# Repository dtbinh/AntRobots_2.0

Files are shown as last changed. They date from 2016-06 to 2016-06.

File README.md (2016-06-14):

# Ant Robot 2.0 #
### Small mobile robots running on Raspberry Pi 2 created to study collective excavation in ant colonies ###

#### Contents of this repository: ####

```arduino_antrobots_2.0/src/``` contains arduino program

```arduino_antrobots_2.0/lib/``` contains library for HMC6343 (3 axis compass)

```CAD_files/``` contains all SolidWorks files

```src/``` contains main c++ raspi code

```Makefile``` contains recipe to compile code in ```src/```

```pixycam.prm``` contains setting for pixy camera

```raspi_setup.txt``` contains all documentation on setup and running

To compile follow these steps in this directory:
```
$ mkdir build		// create a build directory
$ make		        // compile or do 'make rebuild' to recomplie
$ sudo ./run		// run the code
```

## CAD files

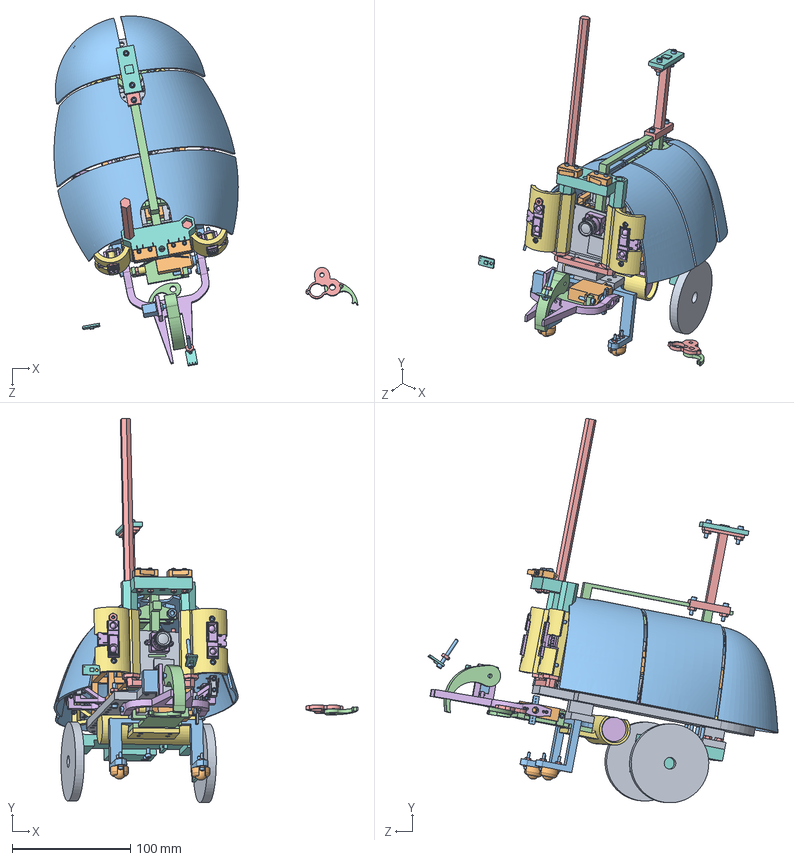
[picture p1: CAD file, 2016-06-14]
CAD_files/DiggerMk2v4d.SLDASM
256.7 x 324.8 x 295.7 mm
ArduinoMega
HS-A5076HB
HS A5076HB square servo hornSLDASM
claw x 2
micro claw base
gripper servo holder
head mount spacer
sparkfun line sensor x 2
Pixy_board
header_2x5ways
mini_usb_b_vertical_connector
RGB_led_CMS
switch-FSMRA6JH
M12_lens_holder
header3x2
header_MTA-100_2pins
pixy_lens
pan head cross recess screw_iso
outer shell 1
shell skeleton
front mount
IR Sensor x 2
front IR mount guard x 2
whisker mount
ModularBodyBase
Metal Ball Caster x 2
front caster holder
arm mount
gyro extention
new side adapter x 4
new side adapter back x 2
quickIMU
quick_switch x 6
quick_switch2 x 2
socket head cap screw_ai x 45
flat washer type a selected narrow_ai x 2
machine screw nut hex_ai x 43
dummy battery
batHolder
dummyWheel x 2
elecHolder
HS-55
grip_hook

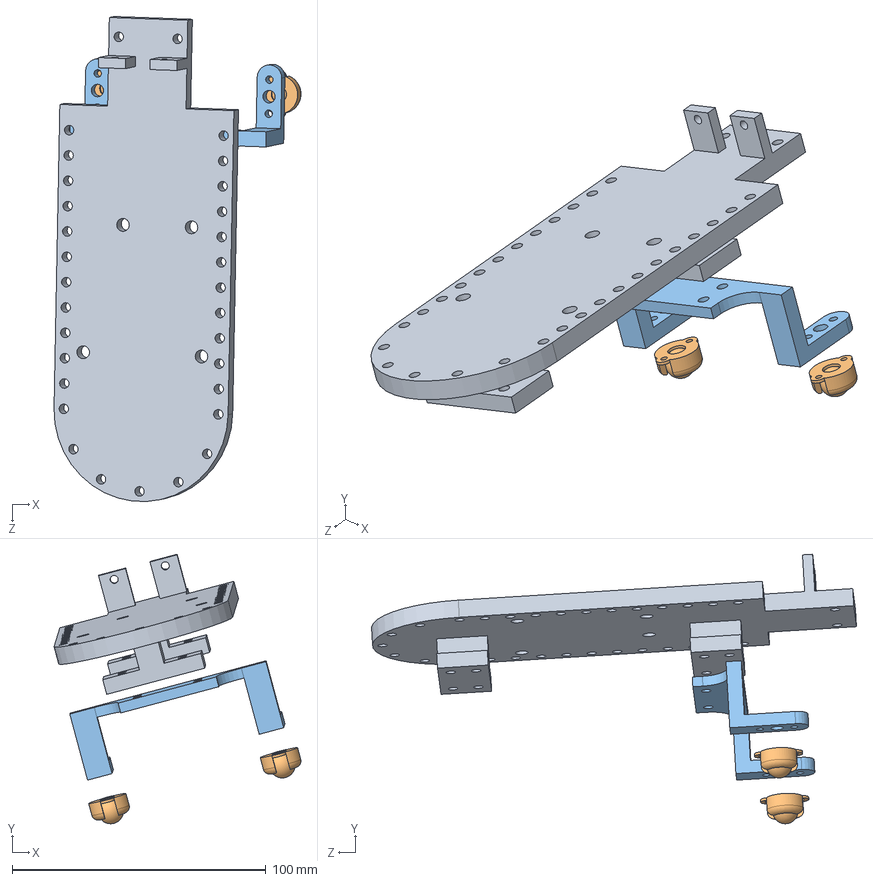
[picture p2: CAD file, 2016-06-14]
CAD_files/Body Assy.SLDASM
97.3 x 106.2 x 191.0 mm
ModularBodyBase
Metal Ball Caster x 2
front caster holder

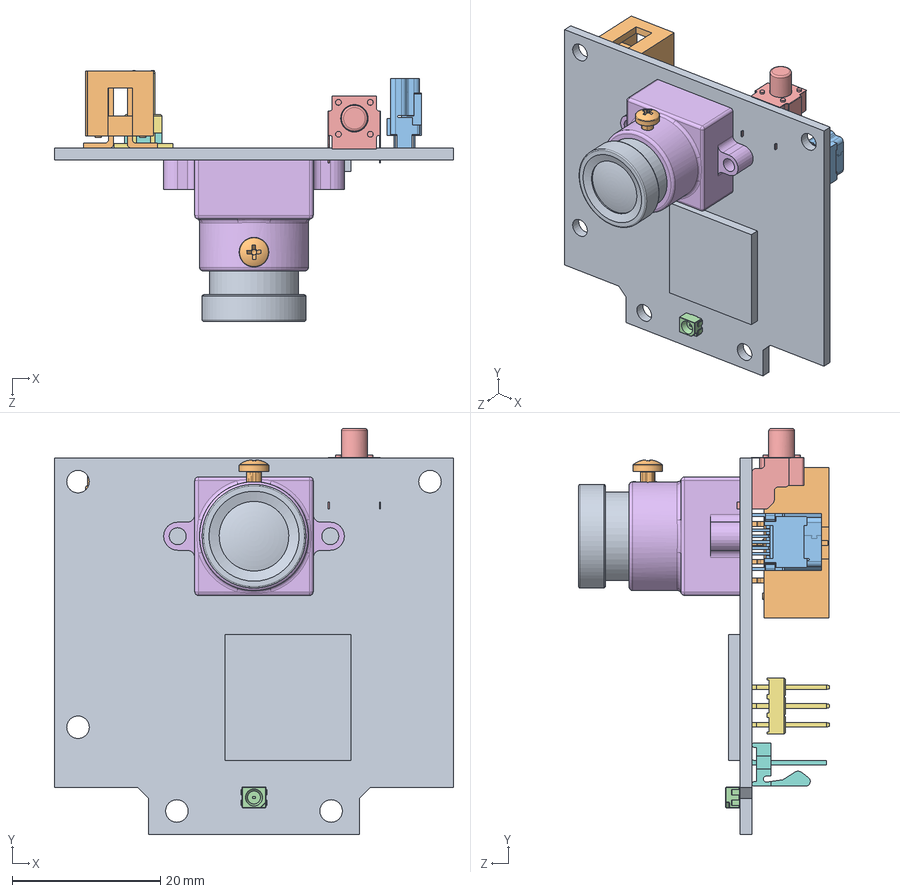
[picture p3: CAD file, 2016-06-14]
CAD_files/Pixy(CMUcam5).SLDASM
53.8 x 54.8 x 33.8 mm
Pixy_board
header_2x5ways
mini_usb_b_vertical_connector
RGB_led_CMS
switch-FSMRA6JH
M12_lens_holder
header3x2
header_MTA-100_2pins
pixy_lens
pan head cross recess screw_iso

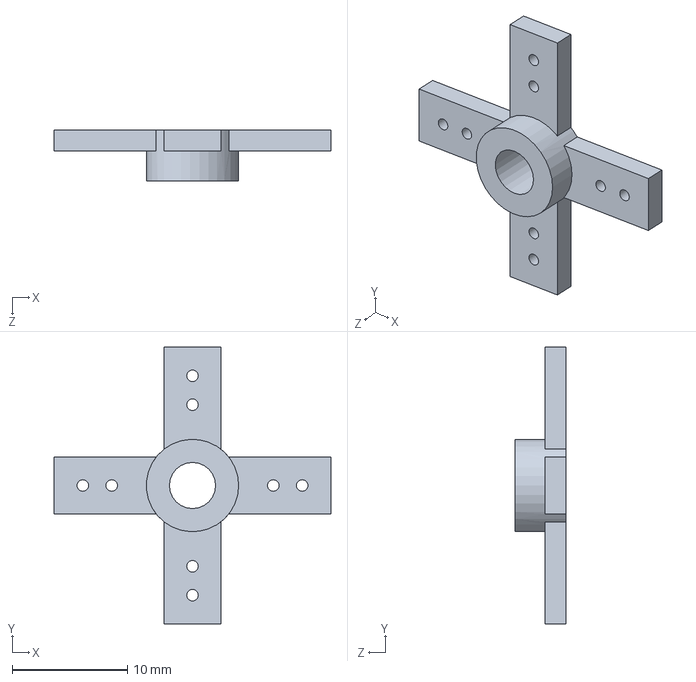
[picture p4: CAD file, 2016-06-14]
CAD_files/HS A5076HB square servo hornSLDASM.SLDPRT
24.0 x 24.0 x 4.40 mm

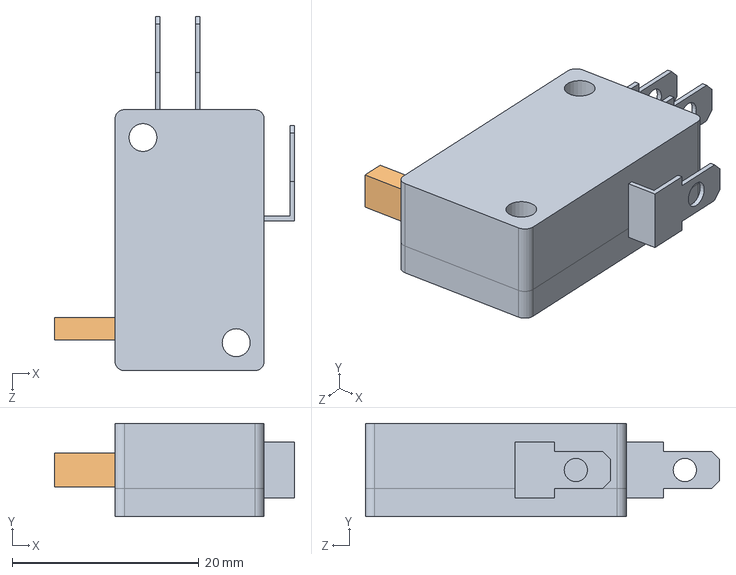
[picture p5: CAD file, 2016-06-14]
CAD_files/hacked limit switch assy.SLDASM
25.7 x 10.0 x 38.0 mm
limit switch body
switch hack

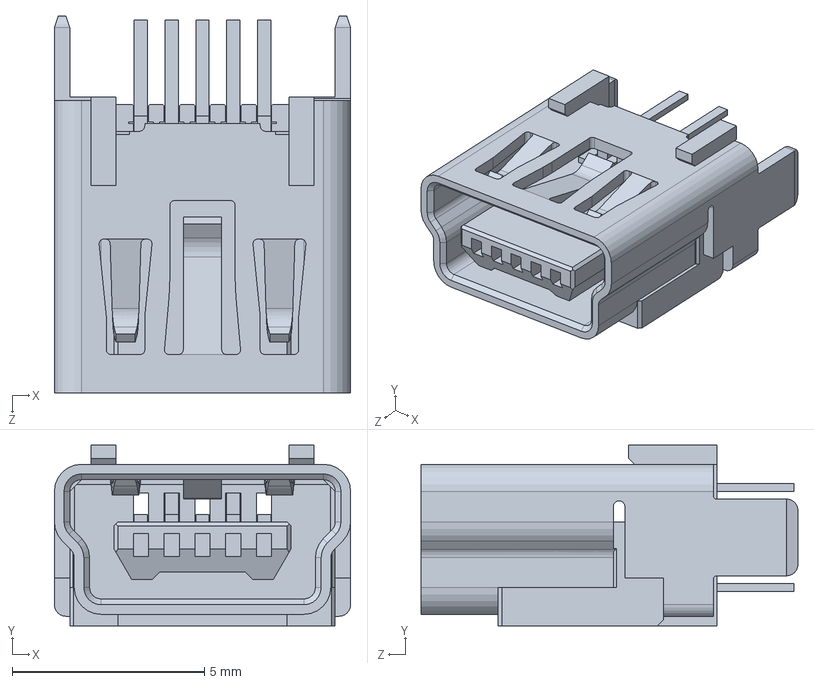
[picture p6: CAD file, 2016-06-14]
CAD_files/mini_usb_b_vertical_connector.SLDPRT
7.70 x 4.70 x 9.80 mm

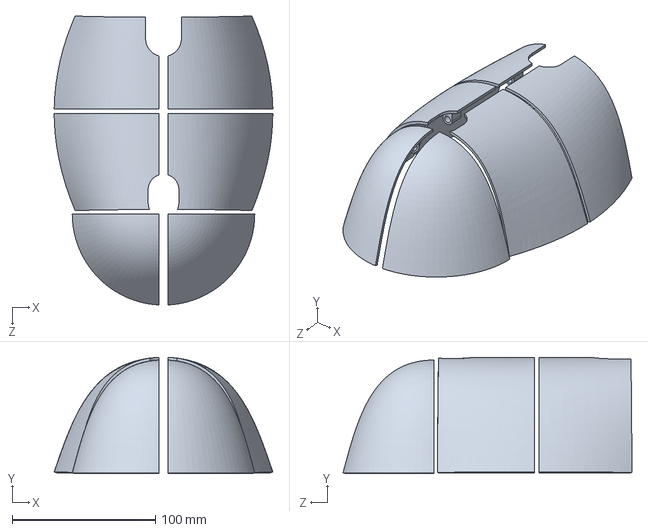
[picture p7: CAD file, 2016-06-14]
CAD_files/outer shell 1.SLDPRT
152.9 x 81.3 x 202.0 mm

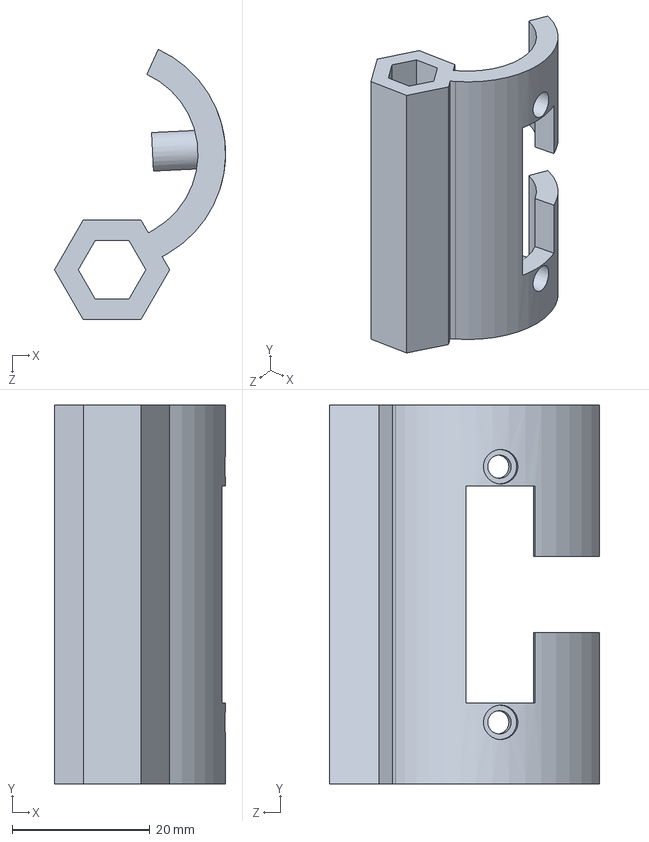
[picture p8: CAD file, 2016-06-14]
CAD_files/front IR mount guard.SLDPRT
24.8 x 55.0 x 39.2 mm

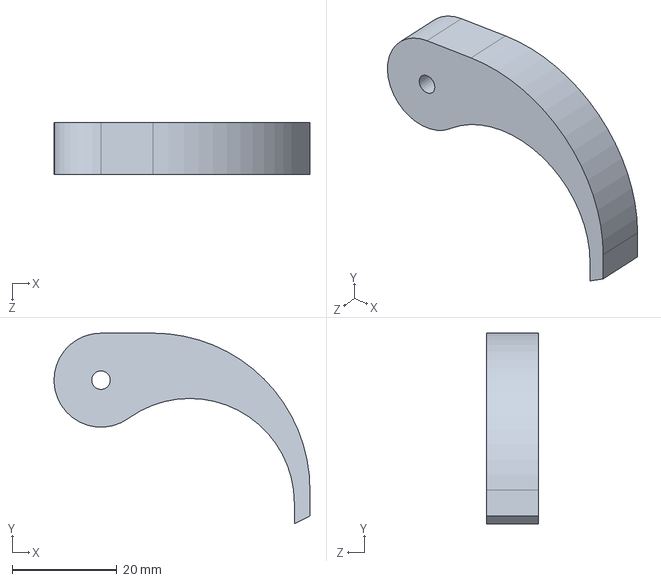
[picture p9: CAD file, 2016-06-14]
CAD_files/grip_hook.SLDPRT
49.0 x 36.5 x 10.0 mm

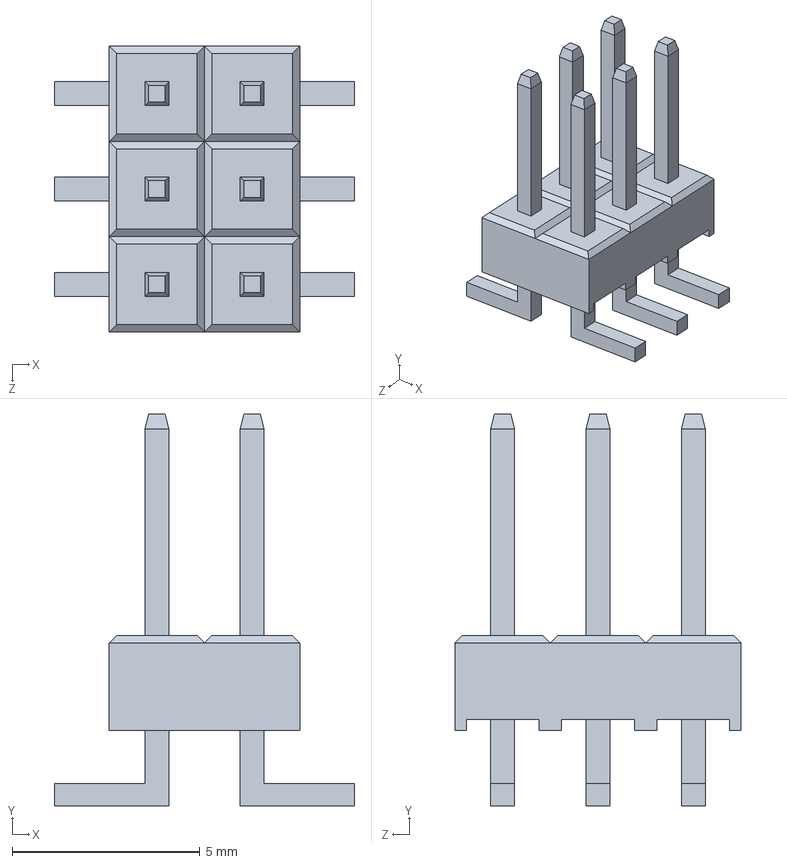
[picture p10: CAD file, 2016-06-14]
CAD_files/header3x2.SLDPRT
8.00 x 10.4 x 7.62 mm

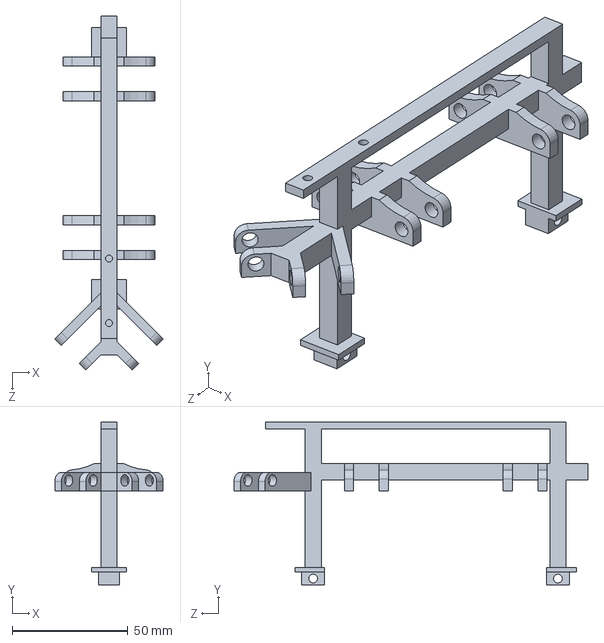
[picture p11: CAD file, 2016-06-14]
CAD_files/shell skeleton.SLDPRT
47.0 x 70.5 x 153.2 mm

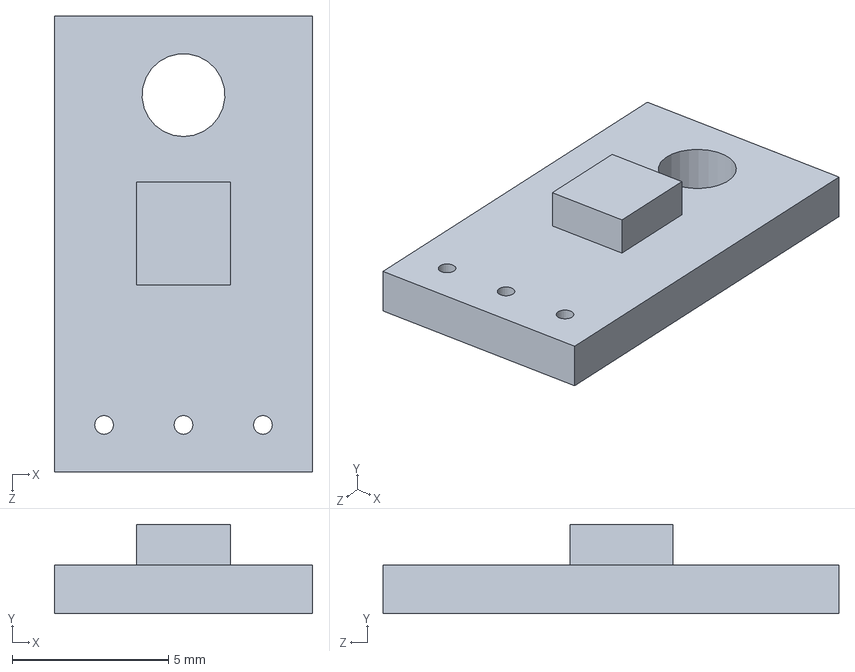
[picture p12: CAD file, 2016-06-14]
CAD_files/sparkfun line sensor.SLDPRT
8.25 x 2.85 x 14.6 mm

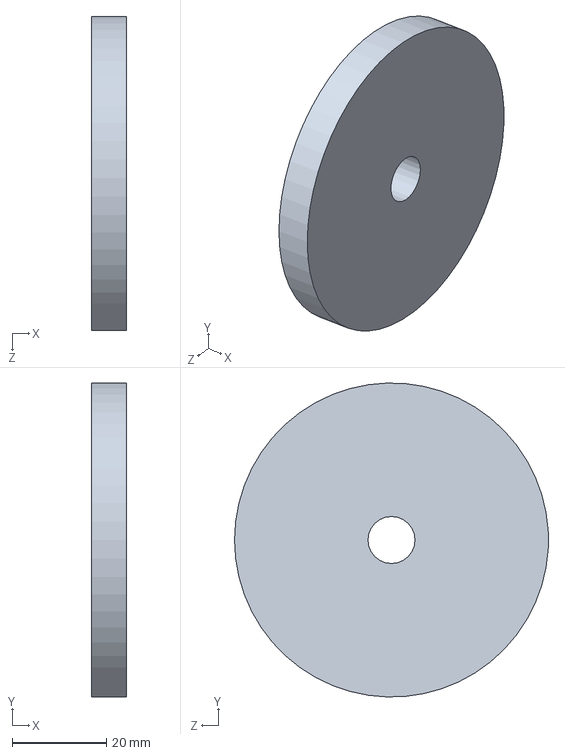
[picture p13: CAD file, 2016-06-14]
CAD_files/dummyWheel.SLDPRT
7.50 x 66.7 x 66.7 mm

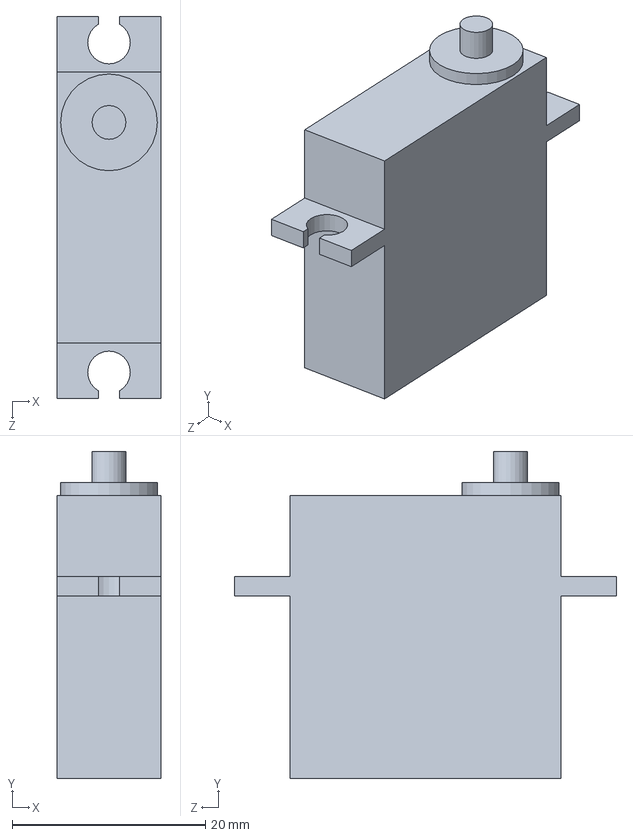
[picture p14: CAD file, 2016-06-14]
CAD_files/HS-A5076HB.SLDPRT
10.8 x 33.8 x 39.5 mm

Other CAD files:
CAD_files/Motor and Wheel.sldasm
CAD_files/ArduinoMega.SLDPRT
CAD_files/micro claw base.SLDPRT
CAD_files/new_ee_holder.SLDPRT
CAD_files/HS-55.SLDPRT
CAD_files/IR Sensor.SLDPRT
CAD_files/M12_lens_holder.SLDPRT
CAD_files/Metal Ball Caster.SLDPRT
CAD_files/ModularBodyBase.SLDPRT
CAD_files/Part2.SLDPRT
CAD_files/Pixy_board.SLDPRT
CAD_files/RGB_led_CMS.SLDPRT
CAD_files/arm mount.SLDPRT
CAD_files/batHolder.SLDPRT
CAD_files/claw.SLDPRT
CAD_files/dummy battery.SLDPRT
CAD_files/elecHolder.SLDPRT
CAD_files/front caster holder.SLDPRT
CAD_files/front mount.SLDPRT
CAD_files/gripper servo holder.SLDPRT
CAD_files/gyro extention.SLDPRT
CAD_files/head mount spacer.SLDPRT
CAD_files/header_2x5ways.SLDPRT
CAD_files/header_MTA-100_2pins.SLDPRT
CAD_files/new side adapter back.SLDPRT
CAD_files/new side adapter.SLDPRT
CAD_files/pixy_lens.SLDPRT
CAD_files/quickIMU.SLDPRT
CAD_files/quick_switch.SLDPRT
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

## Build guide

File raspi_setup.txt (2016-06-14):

/******************************************************
 * @about	Quick set up guide for a new raspberry pi
 * @author	Mustafa Mukadam
 * @date	05-13-2015
 *****************************************************/

1. Erase and remove all partitions on SD card.

2. Download NOOBS from raspi website, unzip and copy contents on SD card.

3. Plug in SD card and turn on raspi. Follow instructions to install Raspbian linux OS.

4. ID: pi, PASSWORD: raspberry. To go into GUI: $ startx

5. Plug in wifi module. On GTwifi use following settings:
	SSID: GTwifi
	Authentication: WAP2-Enterprise (EAP)
	Encryption: CCMP
	EAP method: PEAP
	Identity: user id
	Password: password
	Inner auth: EAP-MSCHAPV2

5. Update after internet connection ready.
	$ sudo apt-get update
	$ sudo apt-get upgrade

6. Raspi setting enable ssh, i2c, spi, serial
	$ sudo raspi-config

7. Get preferred text editor for coding.
	$ sudo apt-get install (geany,vim,emacs)

8. Get C/C++ library to access GPIO.
	bcm2835 (gives access to registers timers, etc):
	http://www.raspberry-projects.com/pi/programming-in-c/c-libraries/bcm2835-by-mike-mccauley
	wiringPi (more high level, arduino like): http://wiringpi.com

	Python library for GPIO also available. Default installed RPi.GPIO. WiringPi2-Python better.

	More info on GPIO stuff: http://elinux.org/RPi_Low-level_peripherals

9. Connect to lab’s robot server
	(SSID:taco truck, no password)
	This network is hidden. Follow steps here to connect to hidden network: http://www.thehecklers.org/2015/02/27/how-to-connect-raspberry-pi-to-hidden-ssid/
	Set up this as a static ip: http://raspberrypi.stackexchange.com/questions/11631/wifi-setup-for-multiple-networks
	$ sudo vim /etc/wpa_supplicant/wpa_supplicant.conf
	$ sudo vim /etc/network/interfaces
	College server for internet should be changed to priority=2 and disabled=1
	Crablab server should be priority=1 and disabled=0
	Switch settings when internet needed.

10. $ ssh 192.168.0.XXX, in putty (install putty if not installed) to access raspi on main computer. (XXX - raspi’s assigned ip address)
	To fix slow ssh connections: http://injustfiveminutes.com/2013/03/13/fixing-ssh-login-long-delay/

11. Have fun coding! Turn off safely when done.
	$ sudo shutdown -h now // or sudo halt
	$ sudo reboot	// to reboot

12. Download current version of antrobots_2.0 source code, complie and run
	$ git clone https://mhmukadam@bitbucket.org/mhmukadam/antrobots_2.0.git
	$ cd antrobots_2.0/
	$ mkdir build
	$ make
	$ sudo ./run

/******************************************************
 * Optional set up and other commands
 *****************************************************/
1. Install git bash on local machine. Git bash provides linux like commands to copy files from the windows local machine to rapis.
	From local machine to raspi
	$ scp /local/path/to/file.blah pi@192.168.0.XXX:~/path/to/file.blah
	From raspi to loacl machine
	$ scp pi@192.168.0.XXX:~/path/to/file.blah ~/path/to/file.blah
	More info and syntax: https://www.garron.me/en/articles/scp.html
	If warning: remote host identification has changed, do this: http://www.cyberciti.biz/faq/warning-remote-host-identification-has-changed-error-and-solution/
	
2. $ free 			// check memory available

3. $ df /			// disk space

4. $ hostname -I	// check ip address

5. $ ifconfig		// check ethernet and wlan connections

6. $ lsusb			// check usb devices connected

7. Vim set up.
	Auto indent and color, put this in ~/.vimrc
	syntax on
	set tabstop=2
	set shiftwidth=2
	set smarttab
	set cindent
	
	For auto brackets completion, download vim plugin from: http://www.vim.org/scripts/script.php?script_id=1849
	put autoclose.vim in ~/.vim/plugin/
	
8. Communication via USB to serial TTL cable
	Red		- Vcc (Pin 4) Caution: Do not power with this wire if micro usb connected
	Black	- GND (Pin 6)
	White	- TX  (Pin 8)
	Green	- RX  (Pin 10)
	Baud rate:		115200
	Bits: 			8
	Parity: 		None
	Stop Bits: 		1
	Flow Control: 	None
	Remember to press enter after putty session begins.
	https://learn.adafruit.com/downloads/pdf/adafruits-raspberry-pi-lesson-5-using-a-console-cable.pdf
	
9. 	Arduino from raspi
	$ sudo apt-get install arduino
	$ sudo apt-get install python-dev
	$ sudo apt-get install python-setuptools
	$ git clone git://github.com/amperka/ino.git
	$ cd ino
	$ sudo make install
	$ sudo python setup.py install
	$ mkdir new_project
	$ cd new_project
	$ ino init -t blink // To make new arduino project

	// Create ino.ini for default settings
	[build]
	board-model = mega2560

	[upload]
	board-model = mega2560
	serial-port = /dev/ttyACM0

	[serial]
	serial-port = /dev/ttyACM0

	$ ino build
	$ ino upload

/******************************************************
 * Robot specs
 *****************************************************/
 Processor: Raspberry Pi 2.0 B, Arduino Mega 2560 via usb to raspi
 Encoders: AS5145H (breakout from madscientisthut.com) via SPI to raspi
 Camera: Pixy via usb to raspi
 Magnetometer: HMC6343 via I2C to arduino
 Gyro: LPY503AL
 5V step up regulator: U3V12F5
 Motor Driver: DRV8835
 Motors: Pololu 120:1 Plastic Gearmotor, Offset Output
 Wheels: Pololu Solarbotics GMPW-B Black Wheel
 Battery: ThruNite 3400mAh Li-ion 3.7V cell (Amazon)

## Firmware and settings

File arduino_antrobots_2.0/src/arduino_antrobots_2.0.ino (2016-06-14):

/**************************************************************************
 * @file	arduino_antrobots_2.0.ino: main program for arduino
 * @about	Implementation of AntRobots 2.0 
 * @author	Mustafa Mukadam
 * @date	05/26/2015	file created
 *
 * (c) Copyright - Georgia Institute of Technology
 *************************************************************************/

/*************************************************************************/
/*********************************includes********************************/
/*************************************************************************/
#include <string.h>
#include <Wire.h>
#include "SFE_HMC6343.h"

/*************************************************************************/
/*********************************defines*********************************/
/*************************************************************************/
#define DEBUG 0

// pin definitions
#define LEFT_MOTOR_PWM 2
#define LEFT_MOTOR_ENABLE 30
#define RIGHT_MOTOR_PWM 3
#define RIGHT_MOTOR_ENABLE 31
#define LED_PIN 13

/*************************************************************************/
/*********************************variables*******************************/
/*************************************************************************/
char rbuf[100];
String rdata;
String data[10];
int pos;
boolean recv_done;
int iter;

unsigned long time_count;
int loop10ms;
int loop200ms;
int loop1000ms;
int tcnt1;

SFE_HMC6343 compass;
int currHeading;

/*************************************************************************/
/******************************check_command******************************/
/*************************************************************************/
void check_command(String rdata) {
	int old_index = -1;
	int index;
	int i = 0;
	int j = 0;
	while ((index = rdata.indexOf(',',old_index+1)) != -1) {
		data[i] = rdata.substring(old_index+1,index);
		i++;
		old_index = index;
	}
	data[i] = rdata.substring(old_index+1);

	// comm test
	if (data[0].equals("test")) {
		Serial.print("Hello Pi ");
		Serial.print(iter);
		Serial.print("$");
		iter++;
	}
	// left mototr
	else if (data[0].equals("lm")) {
		if (data[1].equals("0")) {
			digitalWrite(LEFT_MOTOR_ENABLE,LOW);
			analogWrite(LEFT_MOTOR_PWM,data[2].toInt());
		}
		else {
			digitalWrite(LEFT_MOTOR_ENABLE,HIGH);
			analogWrite(LEFT_MOTOR_PWM,255-data[2].toInt());
		}
	}
	// right motor
	else if (data[0].equals("rm")) {
		if (data[1].equals("0")) {
			digitalWrite(RIGHT_MOTOR_ENABLE,LOW);
			analogWrite(RIGHT_MOTOR_PWM,data[2].toInt());
		}
		else {
			digitalWrite(RIGHT_MOTOR_ENABLE,HIGH);
			analogWrite(RIGHT_MOTOR_PWM,255-data[2].toInt());
		}
	}
	// magnetometer
	else if (data[0].equals("heading")) {
		Serial.print(currHeading);
		Serial.print("$");
	}
}

/*************************************************************************/
/***********************************setup*********************************/
/*************************************************************************/
void setup() {
	// serial comm with pi
	Serial.begin(9600);
	Serial.flush();
	Serial1.begin(115200);
	Serial1.flush();

	pos = 0;
	recv_done = false;
	iter = 1;

	// motors
	pinMode(LEFT_MOTOR_PWM,OUTPUT);
	pinMode(LEFT_MOTOR_ENABLE,OUTPUT);
	digitalWrite(LEFT_MOTOR_ENABLE,LOW);
	analogWrite(LEFT_MOTOR_PWM,0);

	pinMode(RIGHT_MOTOR_PWM,OUTPUT);
	pinMode(RIGHT_MOTOR_ENABLE,OUTPUT);
	digitalWrite(RIGHT_MOTOR_ENABLE,LOW);
	analogWrite(RIGHT_MOTOR_PWM,0);

	pinMode(LED_PIN,OUTPUT);
	time_count = 0;
	loop10ms = 0;
	loop200ms = 0;
	loop1000ms = 0;
	// initialize timer1 
	noInterrupts();           // disable all interrupts
	TCCR1A = 0;
	TCCR1B = 0;

	tcnt1 = 49536;
	TCNT1 = tcnt1;            // preload timer 65536-16MHz
	TCCR1B |= (1 << CS10);    // 16MHz/1 prescaler 
	TIMSK1 |= (1 << TOIE1);   // enable timer overflow interrupt
	interrupts();             // enable all interrupts

	// Initialize the HMC6343 and verify its physical presence
	if (!compass.init()) {
		Serial1.println("HMC6343 Initialization Failed\n\r"); // Report failure, is the sensor wiring correct?
	}

	// ready for raspi
	Serial.print("Ready$");
	#if DEBUG
		Serial1.println("Ready");
	#endif
}

/*************************************************************************/
/***********************************loop**********************************/
/*************************************************************************/
void loop() {
	if (Serial.available()) {
		char c = Serial.read();
		rbuf[pos++] = c;
		if (c == '\0') {
			pos = 0;
			recv_done = true;
		}
	}
	
	if (recv_done) {
		rdata = String(rbuf);
		#if DEBUG
			Serial1.println(rdata);
		#endif
		check_command(rdata);
		recv_done = false;
	}
	
	if (loop10ms) {
		loop10ms = 0;
	}

	if (loop200ms) {
		compass.readHeading();
		currHeading = compass.heading;
		loop200ms = 0;
	}

	if (loop1000ms) {
		loop1000ms = 0;
		digitalWrite(LED_PIN,digitalRead(LED_PIN)^1);
	}
}

/*************************************************************************/
/******************************timer_interrupt****************************/
/*************************************************************************/
ISR(TIMER1_OVF_vect) {
	TCNT1 = tcnt1; // preload timer
	time_count++;
	if ((time_count%10) == 0) {
		loop10ms = 0;
	}
	if ((time_count%200) == 0) {
		loop200ms = 1;
	}
	if ((time_count%1000) == 0) {
		loop1000ms = 0;
	}
}

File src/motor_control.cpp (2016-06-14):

/**************************************************************************
 * @file	motor_control.cpp: coupled PI controller for motors
 * @about	Implementation of AntRobots 2.0 
 * @author	Mustafa Mukadam
 * @date	06/09/2015	file created
 *
 * (c) Copyright - Georgia Institute of Technology
 *************************************************************************/

/*************************************************************************/
/*********************************includes********************************/
/*************************************************************************/
#include <iostream>
#include <cmath>

extern "C" {
#include <unistd.h>
}

#include "defs.h"
#include "motor_control.h"
#include "arduino_comm.h"
#include "encoders.h"

using namespace std;

/*************************************************************************/
/*********************************variables*******************************/
/*************************************************************************/
// extern variables
double vref;
double turn;

// variables only in this file
double e_steer, eL, oldeL, eR, oldeR, intL, intR, uL, uR;

/*************************************************************************/
/****************************motor_control_init***************************/
/*************************************************************************/
void motor_control_init() {
	// initialize variables for coupled PI
	e_steer = 0.0;
	eL = 0.0;
	eR = 0.0;
	oldeL = 0.0;
	oldeR = 0.0;
	intL = 0.0;
	intR = 0.0;
	uL = 0.0;
	uR = 0.0;
	turn = 0.0;
}

/*************************************************************************/
/*****************************motor_send_pwm******************************/
/*************************************************************************/
void motor_send_pwm(char m, int pwm) {
	string sdata;
	if (m == 'l')
		sdata += "lm,";
	else
		sdata += "rm,";
	if (pwm >= 0)
		sdata += "0,";
	else
		sdata += "1,";
	sdata += to_string(abs(pwm));
	send_arduino(sdata);
}

/*************************************************************************/
/********************************stop_motors******************************/
/*************************************************************************/
void stop_motors() {
	motor_send_pwm('l',0);
	motor_send_pwm('r',0);
}

/*************************************************************************/
/***************************coupled PI controller*************************/
/*************************************************************************/
void motor_control(double vel, double trn) {
	e_steer = trn + velR - velL;
	eL = (vel - velL) + (e_steer*KP_TURN_MC);
	eR = (vel - velR) - (e_steer*KP_TURN_MC);
	intL += ((eL + oldeL)*(MC_RATE/2));
	intR += ((eR + oldeR)*(MC_RATE/2));
	uL = (KP_MC*eL) + (KI_MC*intL);
	uR = (KP_MC*eR) + (KI_MC*intR);

	oldeL = eL;
	oldeR = eR;

	// bound inputs and take care of integral wind up
	if (uL > 255) {
		uL = 255;
		intL = 0.99*intL;
	}
	else if (uL < -255) {
		uL = -255;
		intL = 0.99*intL;
	}
	if (uR > 255) {
		uR = 255;
		intR = 0.99*intR;
	}
	else if (uR < -255) {
		uR = -255;
		intR = 0.99*intR;
	}

	// Write inputs to PWM
	motor_send_pwm('l',(int)uL);
	motor_send_pwm('r',(int)uR);
}

/*************************************************************************/
/******************************motor_test*********************************/
/*************************************************************************/
void motor_test() {
	cout<<"***************TESTING MOTORS***************"<<endl;
	motor_send_pwm('l',100);
	cout<<"LEFT MOTOR FORWARD"<<endl;
	sleep(2);
	motor_send_pwm('l',0);
	cout<<"LEFT MOTOR STOP"<<endl;
	sleep(2);
	motor_send_pwm('l',-200);
	cout<<"LEFT MOTOR BACKWARD"<<endl;
	sleep(2);
	motor_send_pwm('l',0);
	cout<<"LEFT MOTOR STOP"<<endl;
	motor_send_pwm('r',100);
	cout<<"RIGHT MOTOR FORWARD"<<endl;
	sleep(2);
	motor_send_pwm('r',0);
	cout<<"RIGHT MOTOR STOP"<<endl;
	sleep(2);
	motor_send_pwm('r',-200);
	cout<<"RIGHT MOTOR BACKWARD"<<endl;
	sleep(2);
	motor_send_pwm('r',0);
	cout<<"RIGHT MOTOR STOP"<<endl;
	cout<<"****************MOTORS TESTED***************"<<endl;
}

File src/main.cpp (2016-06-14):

/**************************************************************************
 * @file	main.cpp: main program
 * @about	Implementation of AntRobots 2.0 
 * @author	Mustafa Mukadam
 * @date	05/26/2015	file created
 *
 * (c) Copyright - Georgia Institute of Technology
 *************************************************************************/

/*************************************************************************/
/*********************************includes********************************/
/*************************************************************************/
#include <iostream>

extern "C" {
#include <bcm2835.h>
#include <stdio.h>
#include <string.h>
#include <sys/time.h>
#include <signal.h>
#include <stdlib.h>
#include <unistd.h>
}

#include "defs.h"
#include "encoders.h"
#include "arduino_comm.h"
#include "motor_control.h"
#include "vision.h"
#include "state_machine.h"

#define TEST 0
#define DEBUG 1

using namespace std;

/*************************************************************************/
/*********************************variables*******************************/
/*************************************************************************/
int time_count = 0;
int loop10ms = 0;
int loop200ms = 0;
int loop1s = 0;
int run_flag = 1;

/*************************************************************************/
/*******************************timer_interrupt***************************/
/*************************************************************************/
void timer_handler(int signum) {
	time_count++;
	loop10ms = 1;
	if ((time_count%20) == 0)
		loop200ms = 1;	
	if ((time_count%100) == 0)
		loop1s = 1;
}

/*************************************************************************/
/*****************************timer_interrupt_init************************/
/*************************************************************************/
void timer_interrupt_init() {
	struct sigaction sa;
	struct itimerval timer;

	/* Install timer_handler as the signal handler for SIGVTALRM. */
	memset(&sa, 0, sizeof (sa));
	sa.sa_handler = &timer_handler;
	sigaction(SIGVTALRM,&sa,NULL);

	timer.it_value.tv_sec = 0;
	timer.it_value.tv_usec = 10000; // timer expires after 10 ms

	timer.it_interval.tv_sec = 0;
	timer.it_interval.tv_usec = 10000; // timer expires every 10 ms

	setitimer(ITIMER_VIRTUAL,&timer,NULL);
}

/*************************************************************************/
/*****************************handle Ctrl+C signal************************/
/*************************************************************************/
void my_handler(int s) {
	run_flag = 0;
}

/*************************************************************************/
/************************************main*********************************/
/*************************************************************************/
int main(int argc, char **argv) {
	//*****load raspi gpio
	if (!bcm2835_init())
		return 1;
	
	//*****start spi for all connected devices
	bcm2835_spi_begin();
	
	//*****establish serial with arduino
	if (!arduino_comm_init())
		cout<<"Connection with Arduino not established"<<endl;
	#if TEST
		arduino_comm_test(); // test comm with arduino
	#endif

	//*****setup for handling Ctrl+C signal
	struct sigaction sigIntHandler;
	sigIntHandler.sa_handler = my_handler;
	sigemptyset(&sigIntHandler.sa_mask);
	sigIntHandler.sa_flags = 0;
	sigaction(SIGINT,&sigIntHandler,NULL);

	//*****initialize encoders (uses SPI)
	encoders_init();
	#if TEST
		encoders_test(); // test encoders
	#endif
	#if TEST
		motor_test(); // test motors
	#endif
	
	//*****load Pixy
	int pixy_init_status = pixy_init();
	if(!pixy_init_status == 0) { // handle error initializing pixy
		printf("pixy_init(): ");
		pixy_error(pixy_init_status);
		return pixy_init_status;
	}
	#if TEST
		camera_test(); // test camera
	#endif

	//*****heading
	#if TEST
		heading_test(); // test camera
	#endif

	//*****initialize motor controller variables
	motor_control_init();
	//*****initialize trail following variables
	follow_trail_init();
	
	//*****initialize timer interrupt
	timer_interrupt_init();

	//*****state machine loop
	vref = 30.0;
	turn = 0.0;
	curr_state = GOING_IN;
	prev_state = GOING_IN;
	while (run_flag) {
		if (loop10ms) {
			encoders_read();
			encoders_cal_vel();
			read_camera();
			update_state();
			execute_state();
			loop10ms = 0;
		}
		if (loop200ms) {
			heading_read();
			loop200ms = 0;
		}
		if (loop1s) {
			//blocksData[PH_END].print_blockData();
			std::cout<<"State: "<<curr_state<<",\t"<<"Left Vel:"<<velL<<",\t"<<"Right Vel:"<<velR<<",\t"<<"Turn:"<<turn<<",\t"<<"Heading:"<<heading<<std::endl;
			loop1s = 0;
		}
	}	

	//*****stop and close everything after Ctrl+C signal
	stop_motors(); // stop motors
	pixy_close(); // close pixy camera
	bcm2835_spi_end(); // end spi
	bcm2835_close(); // close raspi gpio
	return 0;
}

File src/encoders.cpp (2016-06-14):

/**************************************************************************
 * @file	main.cpp: read AS5145H magnetic encoders
 * @about	Implementation of AntRobots 2.0 
 * @author	Mustafa Mukadam
 * @date	05/26/2015	file created
 *
 * (c) Copyright - Georgia Institute of Technology
 *************************************************************************/

/*************************************************************************/
/*********************************includes********************************/
/*************************************************************************/
#include <iostream>
#include <cmath>
#include <iomanip>

extern "C" {
#include <bcm2835.h>
}

#include "defs.h"
#include "encoders.h"

using namespace std;

/*************************************************************************/
/*********************************variables*******************************/
/*************************************************************************/
// extern variables
unsigned int encL;
unsigned int encR;
double velL;
double velR;

// variables only in this file
long Angle1;
long Angle2;
long oldAngle1;
long oldAngle2;
int digitalAngle1;
int digitalAngle2;
int OlddigitalAngle1;
int OlddigitalAngle2;
int firstAngle1;
int firstAngle2;
int initialAngle1;
int initialAngle2;

/*************************************************************************/
/******************************encoders_init******************************/
/*************************************************************************/
void encoders_init() {
	// chip select pin as output and inactive HIGH
	bcm2835_gpio_fsel(CS_ENCODER_L,BCM2835_GPIO_FSEL_OUTP);
	bcm2835_gpio_write(CS_ENCODER_L,HIGH);
	bcm2835_gpio_fsel(CS_ENCODER_R,BCM2835_GPIO_FSEL_OUTP);
	bcm2835_gpio_write(CS_ENCODER_R,HIGH);

	// initialize variables
	encL = 0;
	encR = 0;
	velL = 0.0;
	velR = 0.0;

	Angle1 = 0;
	Angle2 = 0;
	oldAngle1 = 0;
	oldAngle2 = 0;
	OlddigitalAngle1 = 0;
	OlddigitalAngle2 = 0;
	firstAngle1 = 1;
	firstAngle2 = 1;
	initialAngle1 = 0;
	initialAngle2 = 0;
}

/*************************************************************************/
/******************************encoders_read******************************/
/*************************************************************************/
void encoders_read() {
	bcm2835_spi_setBitOrder(BCM2835_SPI_BIT_ORDER_MSBFIRST); // MSBFIRST
	bcm2835_spi_setDataMode(BCM2835_SPI_MODE3); // polarity=1, phase=1
	bcm2835_spi_setClockDivider(BCM2835_SPI_CLOCK_DIVIDER_256); // 1MHz

	char buf[3];
	bcm2835_gpio_write(CS_ENCODER_L,LOW); // start reading
	bcm2835_spi_transfern(&buf[0],3);
	bcm2835_gpio_write(CS_ENCODER_L,HIGH); // end reading
	// get encoder count from first 12 MSB (4096 ticks/rev)
	encL = (((unsigned int)(buf[0] & 0x7F))<<5) + (((unsigned int)(buf[1] & 0xF8))>>3);

	bcm2835_gpio_write(CS_ENCODER_R,LOW); // start reading
	bcm2835_spi_transfern(&buf[0],3);
	bcm2835_gpio_write(CS_ENCODER_R,HIGH); // end reading
	// get encoder count from first 12 MSB (4096 ticks/rev)
	encR = (((unsigned int)(buf[0] & 0x7F))<<5) + (((unsigned int)(buf[1] & 0xF8))>>3);

	digitalAngle1 = encL;
	digitalAngle2 = encR;
}

/*************************************************************************/
/*****************************encoders_cal_vel****************************/
/*************************************************************************/
void encoders_cal_vel() {
	if (firstAngle2 == 1) {
		firstAngle2 = 0;
		Angle2 = digitalAngle2;
		OlddigitalAngle2 = digitalAngle2;
		initialAngle2 = digitalAngle2;
		oldAngle2 = initialAngle2;
	}
	else {
		if (abs(digitalAngle2-OlddigitalAngle2) > 1000) {  // 1000 number figured for 2ms sample rate and max speed
			// we have roll over
			if (digitalAngle2 > OlddigitalAngle2) {
				Angle2 = Angle2 - (OlddigitalAngle2) - (4096-digitalAngle2);
			}
			else {
				Angle2 = Angle2 + (4096-OlddigitalAngle2) + (digitalAngle2);
			}
		}
		else { // no roll over
			Angle2 = Angle2 + (digitalAngle2-OlddigitalAngle2);
		}
		OlddigitalAngle2 = digitalAngle2;
	}

	if (firstAngle1 == 1) {
		firstAngle1 = 0;
		Angle1 = digitalAngle1;
		OlddigitalAngle1 = digitalAngle1;
		initialAngle1 = digitalAngle1;
		oldAngle1 = initialAngle1;
	}
	else { // signs are reversed here as the left encoder is reversed
		if (abs(digitalAngle1-OlddigitalAngle1) > 1000) {  // 1000 number figured for 2ms sample rate and max speed
			// we have roll over
			if (digitalAngle1 > OlddigitalAngle1) { // Going reverse
				Angle1 = Angle1 + (OlddigitalAngle1) + (4096-digitalAngle1);
			}
			else { // Going forward
				Angle1 = Angle1 - (4096-OlddigitalAngle1) - (digitalAngle1);
			}
		}
		else { // no roll over
			Angle1 = Angle1 - (digitalAngle1-OlddigitalAngle1);
		}
		OlddigitalAngle1 = digitalAngle1;
	}

	// velocity calculation
	velL = (Angle1 - oldAngle1)/(VEL_CNV_CMPS*ENC_SAMPLE_RATE);
	velR = (Angle2 - oldAngle2)/(VEL_CNV_CMPS*ENC_SAMPLE_RATE);
	oldAngle1 = Angle1;
	oldAngle2 = Angle2;
}

/*************************************************************************/
/********************************encoders_test****************************/
/*************************************************************************/
void encoders_test() {
	long count = 0;
	std::cout<<"**************TESTING ENCODERS**************"<<std::endl;
	std::cout<<std::setprecision(2)<<std::fixed;
	while(count <= TESTTIME/2) {
		encoders_read();
		encoders_cal_vel();
		if (count%250 == 0) {
			std::cout<<"Left Enc:"<<encL<<",\t"<<"Right Enc:"<<encR<<"\t|| ";
			std::cout<<"Left Vel:"<<velL<<",\t"<<"Right Vel:"<<velR<<std::endl;
		}
		count++;
		bcm2835_delay(2);
	}
	std::cout<<"**************ENCODERS TESTED***************"<<std::endl;
}
